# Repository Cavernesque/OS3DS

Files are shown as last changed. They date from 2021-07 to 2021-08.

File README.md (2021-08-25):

# Open Source 3D Scanner - OS3DS

The Open Source 3D scanner is a project with the aims to develop a low-cost, open source hardware and software 3D LiDAR scanner.
This project is an academic research project with MacEwan University, with funding from the Office of Research Services Undergraduate Student Research Initiative Grant (USRI).

### The Project Team

The project team consists of:

- Darren Paetz - Software and Electrical design
- Matt Kantor - Mechanical and Software design
- Dr. Philip Mees - Project Mentor
- Dr. Jeffrey Davis - Project Mentor

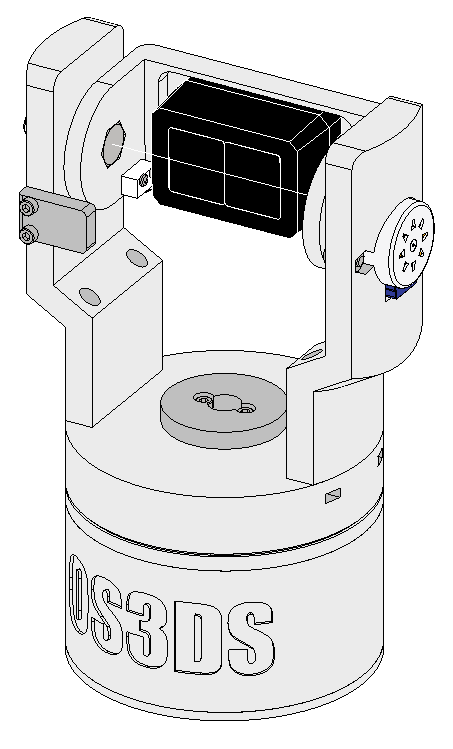
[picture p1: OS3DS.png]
The OS3DS


## The Hardware

The OS3DS has several key hardware components.

It has an Arduino Uno for I/O management, the Benewake TF-02 Pro/Mini Plus for LiDAR data acquisition, 2 5V 28BYJ-48 Stepper motors (64:1) to control its position, and has a 3D printed (PLA and PETG) enclosure that allows proper cable management and tripod mounting.

All of the 3D models for this project can be found in the Electrical_Mechanical folder.

An electrical schematic is included for reference in construction.

Full details of the hardware design can be found in the Design Report, which is located in the Design_Report folder.

## The Software

The OS3DS firmware is written in the Arduino flavor of C++.

Scanner parameters are fully software configurable from the included application. The application can either be built directly from the included Python module, or can be run from the included compressed .7z archive which includes a .exe build of the application.

The included Python module provides a GUI that you can use to send configuration data to the scanner and also then read the scan data back from the Arduino. It saves scan information in the platform-agnostic and ASTM standardized .E57 format, as well as to a file in ASCII format for manipulation and direct viewing.

##### Python Dependencies
- numpy
- pye57
- serial
- PyQt5

## Contribution
Anyone and everyone is free and encouraged to build upon the work this project has started! If any issues are found, please create an issue so that it can be seen by the project owners and the community.

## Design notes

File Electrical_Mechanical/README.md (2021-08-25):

# Print Settings

MATERIAL:  PETG, ABS, or PLA+ (This is due to heat generated by stepper motors, it may exceed the thermal stability of Standard PLA if the motors stall out) 

NOTES:
For best results, print all parts in the default orientation.
Enclosure_Top, and Rotating_Base MUST be printed at 0.2mm layer height or finer.

## Schematic
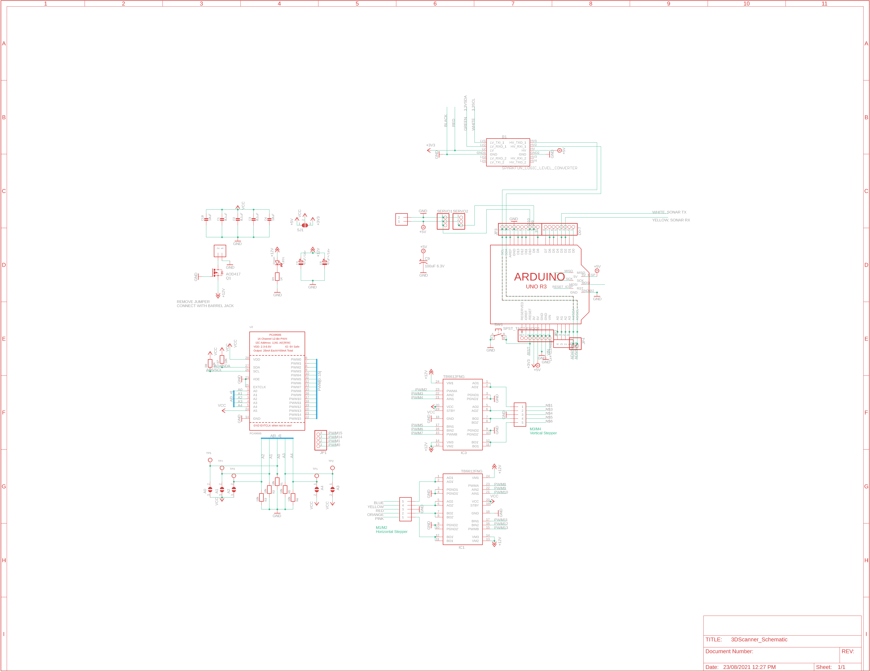
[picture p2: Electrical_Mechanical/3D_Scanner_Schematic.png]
Electrical Schematic


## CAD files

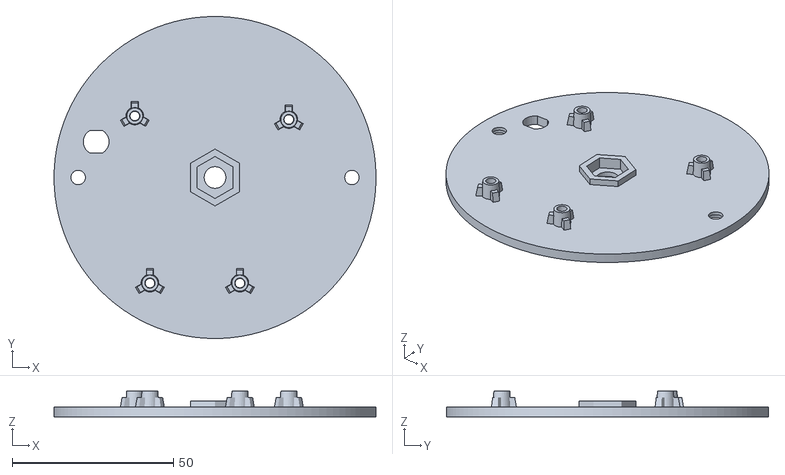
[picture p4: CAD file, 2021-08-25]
Electrical_Mechanical/STL_Files/Base_Plate.stl
100.0 x 100.0 x 8.00

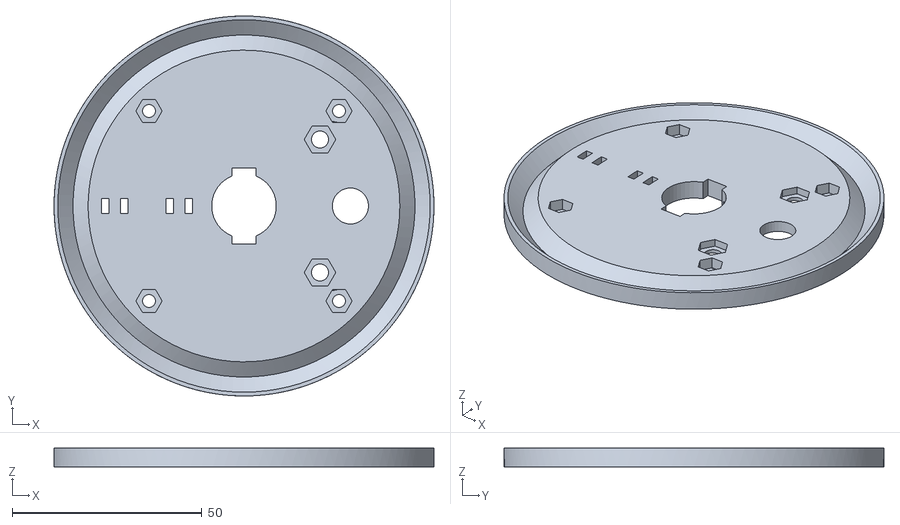
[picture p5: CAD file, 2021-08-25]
Electrical_Mechanical/STL_Files/Enclosure_Top.stl
100.0 x 100.0 x 5.00

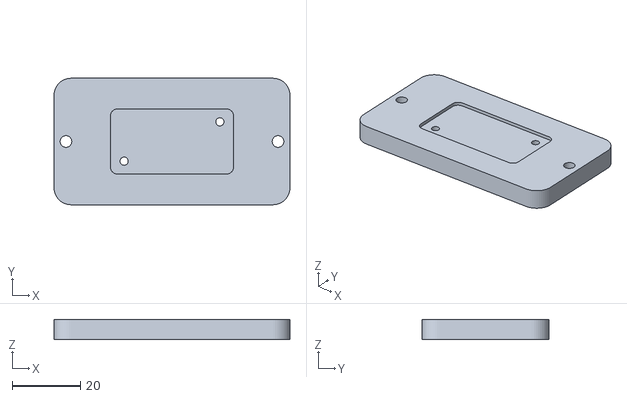
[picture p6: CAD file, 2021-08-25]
Electrical_Mechanical/STL_Files/TFMINI_PLUS_AdapterPlate.stl
69.0 x 37.0 x 5.90

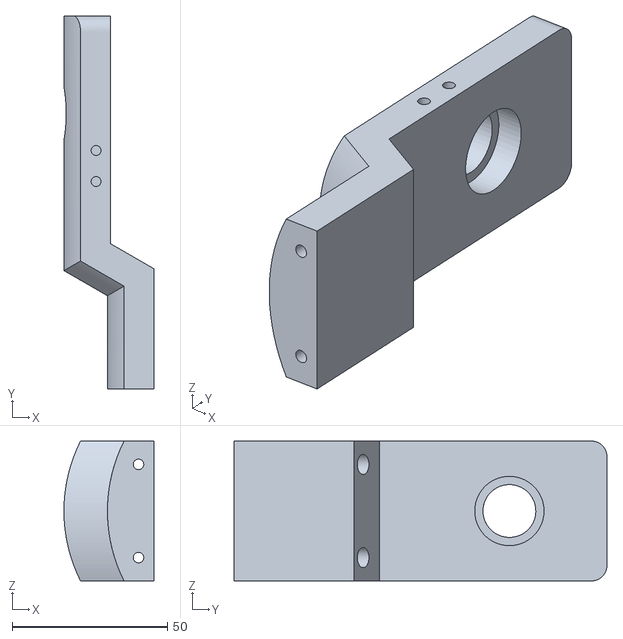
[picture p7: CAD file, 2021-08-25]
Electrical_Mechanical/STL_Files/BearingArm.stl
29.0 x 120.0 x 45.0

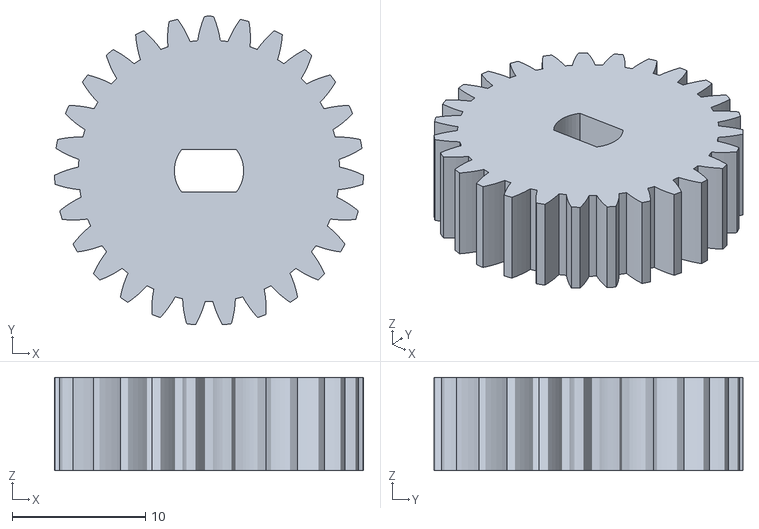
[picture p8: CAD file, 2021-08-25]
Electrical_Mechanical/STL_Files/Spur _Gear.stl
23.2 x 23.2 x 7.00

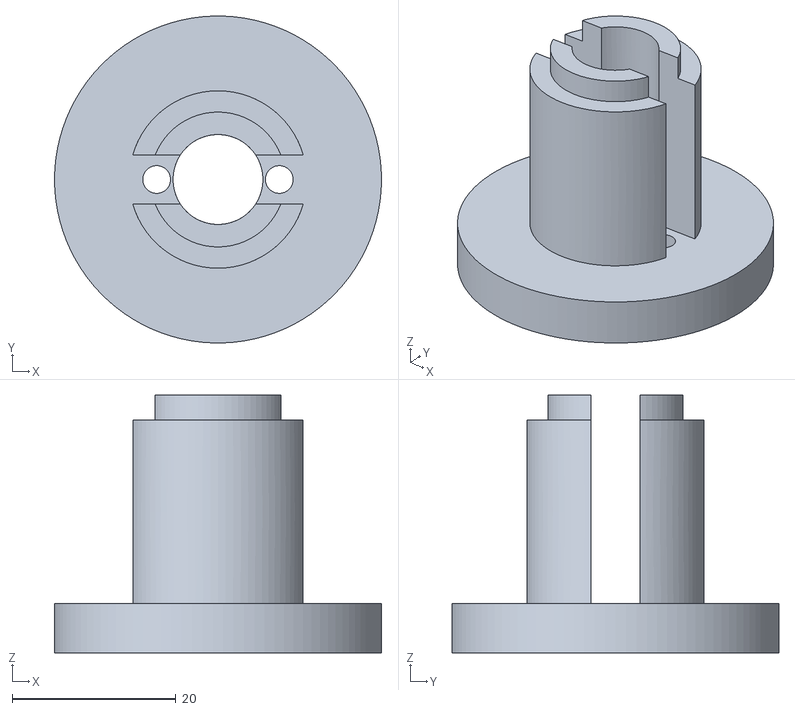
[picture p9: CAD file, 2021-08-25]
Electrical_Mechanical/STL_Files/Shaft.stl
40.0 x 40.0 x 31.5

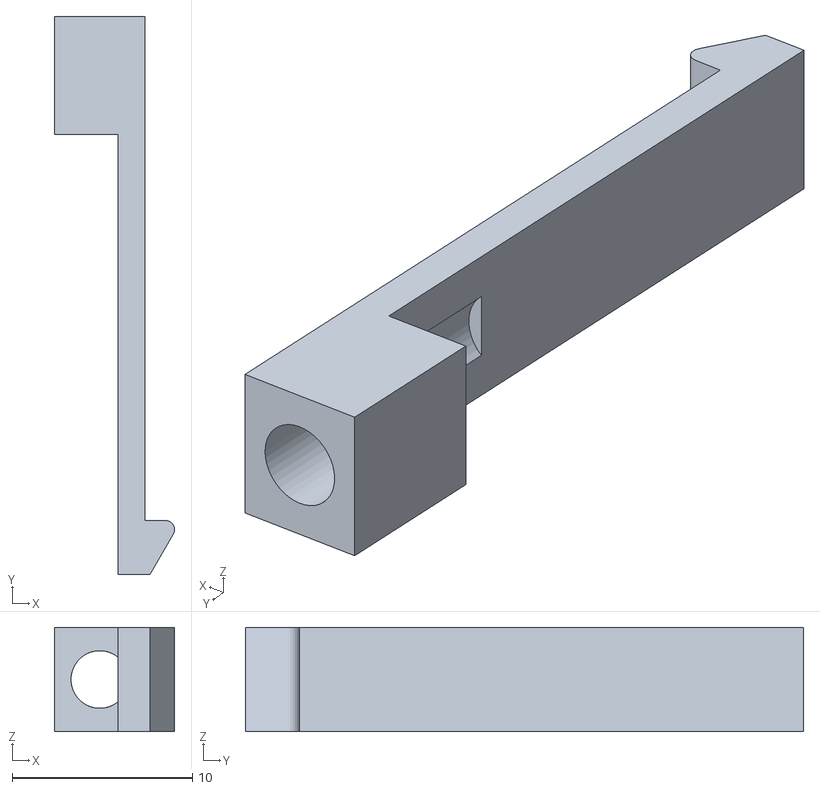
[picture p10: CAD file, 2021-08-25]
Electrical_Mechanical/STL_Files/Shaft Hook.stl
6.68 x 31.0 x 5.80

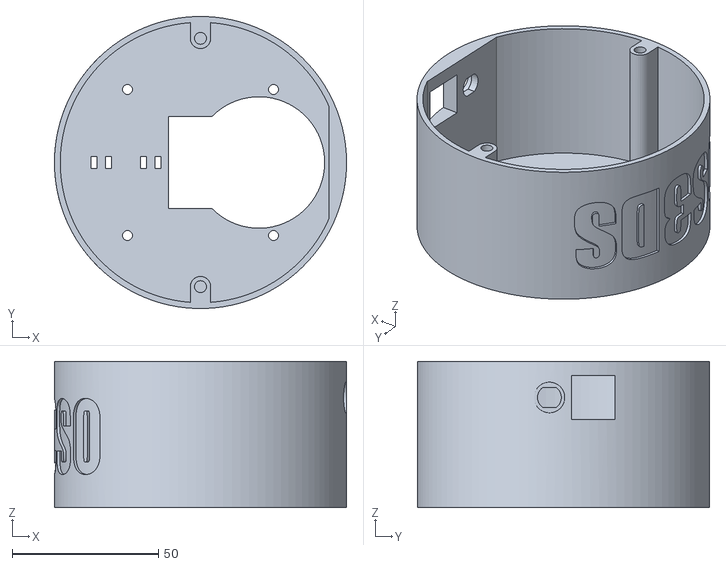
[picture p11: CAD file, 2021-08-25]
Electrical_Mechanical/STL_Files/Enclosure_Body.stl
100.0 x 100.0 x 50.0

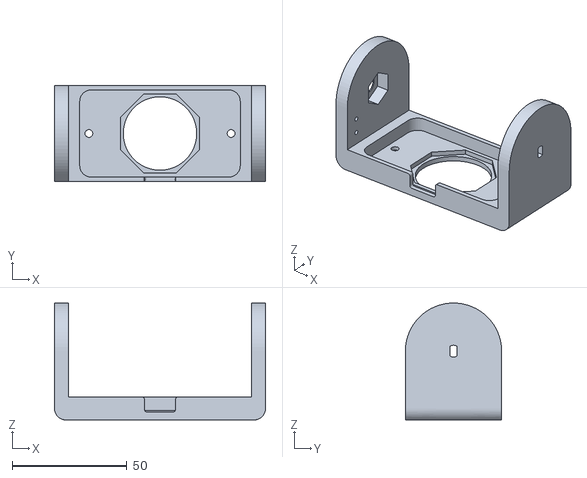
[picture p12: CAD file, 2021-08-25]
Electrical_Mechanical/STL_Files/Sensor_Brkt.stl
92.0 x 42.0 x 51.0

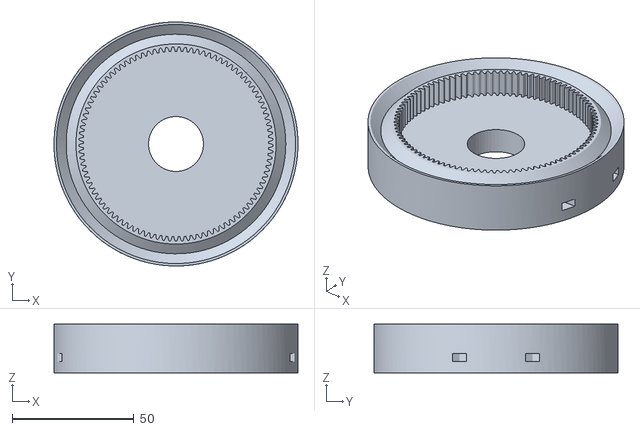
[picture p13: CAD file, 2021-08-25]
Electrical_Mechanical/STL_Files/Rotating_Base.stl
100.0 x 100.0 x 20.0

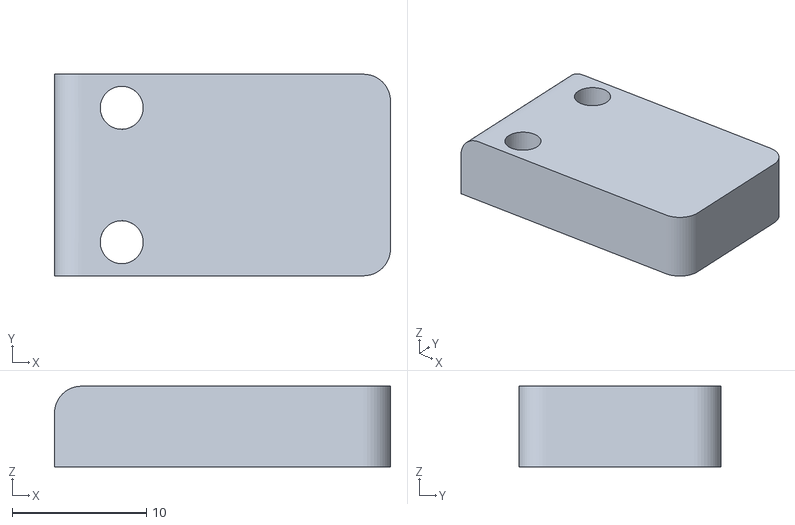
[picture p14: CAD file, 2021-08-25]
Electrical_Mechanical/STL_Files/Endstop_Block.stl
25.0 x 15.0 x 6.00

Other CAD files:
Electrical_Mechanical/STL_Files/Stepper_Arm.stl

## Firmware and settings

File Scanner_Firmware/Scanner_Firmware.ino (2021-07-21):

/*
 * Open-Source 3D Scanner Project
 * Summer 2021
 * Darren Paetz, Matt Kantor, Philip Mees
 * MacEwan University, Edmonton, Alberta, Canada, 2021
 * 
 * This firmware is designed to be used with the 3D Scanner Interface application.
 * That application will gather the data from the scanner and convert it to an
 * industry standard file format (E57).
 * 
 * 
 */

#include <Wire.h>
#include <Adafruit_MotorShield.h>
#include <SoftwareSerial.h>

/***************
  Globals
***************/
// --Scanner--
// Parameters
unsigned int sensor_type = 0; // Parameterization from app - MEMSAVE: byte
unsigned int scan_angle = 0; // Parameterization from app
float scan_resolution = 0; // Parameterization from app
// Scanner angle limits
//  Angle phi is measured downwards from the zenith, relative to the vertical axis of the scanner
//  Straight up (Zenith) -> 0°   Straight down (Nadir) -> 180°
//  Max vertical (highside_angle): 0, but realistically should be 15 degrees.
//  Min vertical (lowside_angle): 150, limited by scanner body.
unsigned int highside_angle = 20;  // Parameterization from app
unsigned int lowside_angle = 135;  // Parameterization from app
unsigned int scan_point_trimming = 0;  // Parameterization from app
unsigned int scan_data_validation = 0; // Parameterization from app
// Scanner data collection
unsigned int distance = 0; // Distance will be used by either sensor type, and takes the same form in memory.
unsigned int intensity = 0; // Strength will be used exclusively by the LiDAR, both TF02 Pro and TFMini
// Scan statistics and flags
bool scan_complete = false;  // Flag for scan completion status
bool scanner_configured = false;  // Flag for scanner successful configuration
byte scanner_current_line = 1;  // Tracks current line to adjust for point interpolation.
unsigned int scan_points_acquired = 0;  // Tracks how many points have currently been scanned.
unsigned long anticipated_points = 0;  // Calculated number of points scan parameters should yield.
unsigned int validation_fails = 0;  // Tracks amount of failed transmissions from sensors
unsigned long vertical_step_cnt = 0;  // Tracks the number of steps to travel back to the top

// ----External Devices----
// --Steppers--
// We'll be using the steppers in full step mode, meaning we get 2037 steps per revolution
// This is based on independent findings that the 28BYJ-48 stepper has 4074 steps per full revolution in half step mode
const int revolution_steps = 2037; // 2037 steps per revolution of stepper (11.311 degrees/64:1 gear ratio)
const float horiz_deg_steps = 20.0871; // 20.0871 steps per horizontal degree (with scanner gearing)
const float vert_deg_steps = 5.6583; // 5.6583 steps per vertical degree (only stepper gearing)
const int full_steps = 7342; // 7342 steps per full horizontal revolution of scanner
float horiz_position = 0; // Initialize horizontal position tracking variable
float vert_position = 90; // Initialize vertical position tracking variable, will be set during homingSequence
bool vert_motor_direction = true; // Vertical motor direction: False is up, True is down

// --LiDAR--
// Default address of the LiDAR is 0x10 (DEC: 16)
// MEMSAVE: Place only in PROGMEM
int lid_addr = 0x10; // Leave as variable so it can be configured to prevent address collisions

/********************
 Stepper object setup
********************/
//Use default I2C addr 0x60 (DEC: 96)
Adafruit_MotorShield AFMS = Adafruit_MotorShield(); 
//Create stepper object with (Steps/rev,Motor Port) on Motor Port 1 (M1&M2) and 2 (M3&M4) 
Adafruit_StepperMotor *horiz_Stepper = AFMS.getStepper(revolution_steps,1); 
Adafruit_StepperMotor *vert_Stepper = AFMS.getStepper(revolution_steps,2);

/******************
 Physical I/O setup
******************/
// Reserve serial connection for the sonar if used
SoftwareSerial sonar_Serial(2,3); // RX 2, TX 3
// Limit switch for vertical axis
const int limit_pin = 7;

/*****************
 Initial functions
*****************/
void setup() {
  // Open serial connection to the application.
  Serial.begin(115200);
  // We'll always need motorshield communication, start it immediately.
  AFMS.begin();
  // Default Stepper Speed is 10 RPM
  horiz_Stepper->setSpeed(10);  // TEST: Change to 15 rpm?
  vert_Stepper->setSpeed(10);  // TEST: Change to 15 rpm?
  // Set pins for limit switch and sonar serial connection
  pinMode(limit_pin, INPUT_PULLUP);
  pinMode(2, INPUT);
  pinMode(3, OUTPUT);
}

void serialEvent(){
  /*  The first character of any serial transmission will be a command code.
   *  A: Configure scanner
   *  B: Jog motors
   *  C: Scan
   *  D: Rangefind
   *  serialEvent is only called at the end of loop(), so we don't need to worry about
   *  potentially interfering with a configuration frame once in that function.
   */
  char command_code = (char)Serial.read();
  switch(command_code){
    case 65:
      codeAConfigure();
      break;
    case 66:
      codeBJog();
      break;
    case 67:
      codeCScan();
      break;
    case 68:
      codeDRangefind();
      break;
  }
}

/***************************
 Configuration (A) functions
***************************/

void codeAConfigure(){
  bool get_config = false, begin_scan = false;
  // Purge the serial buffer to prepare to read configuration data
  while(Serial.available()){
    char byte_dump = Serial.read();
  }
  // Until we can successfully read a configuration frame from the application, do nothing.
  while(get_config == false){
    get_config = getConfiguration();
  }
  // Until we can successfully get a confirmation message from the application, do nothing.
  while(begin_scan == false){
    begin_scan = confirmScan();
  }
  // We've configured successfully, proceed to scan. Set the serial timeout to match the application.
  Serial.setTimeout(500);
  // sensor_type 0 -> SONAR
  //             1 -> LiDAR
  switch(sensor_type){
    case 0: // Sonar
      pinMode(2,INPUT);
      pinMode(3,OUTPUT);
      sonar_Serial.begin(9600);
      sonar_Serial.listen();
      break;
    case 1: // Lidar
      // Begin takes the argument of the Slave address for Arduino to take
      // If no address is given, it joins the I2C bus as a Master
      Wire.begin();
      // Set the wire clock to Fast mode, 400kbps
      Wire.setClock(400000);
      // Set up I2C communication mode to LiDAR
      Wire.beginTransmission(lid_addr);
      // Write the command to change the measurement unit to mm instead of cm
      // HEX: {5A, 05, 05, 06, 6A}     DEC: {90, 5, 5, 6, 106}
      byte message[] = {90, 5, 5, 6, 106};
      Wire.write(message,5);
      // TODO: Add in a message to change the slave address of the I2C if necessary
      // 210618, DP: Likely unnecessary.
      Wire.endTransmission();
      delay(10);  // Wait minimum time for LiDAR response
      break;
  }
  anticipated_points = calcScanPoints();
  homingSequence();
}

bool getConfiguration(){
  /*  Listen on the USB UART for configuration data from the application
   *  Save settings to globals
   *  If data has an invalid parameter, pass back false
   */
  String sensor_string = "", angle_string = "", hiangle_string = "";
  String loangle_string = "", resolution_string = "", valid_string = "", trim_string = "";
  // Set the serial timeout to be very long to allow for potential manual configuration
  // Get configuration data from the application
  // Leave 10ms in between reads to give time for the serial buffer to fill
  Serial.setTimeout(10000);
  sensor_string = Serial.readStringUntil('\n');
  delay(10);
  angle_string = Serial.readStringUntil('\n');
  delay(10);
  hiangle_string = Serial.readStringUntil('\n');
  delay(10);
  loangle_string = Serial.readStringUntil('\n');
  delay(10);
  resolution_string = Serial.readStringUntil('\n');
  delay(10);
  valid_string = Serial.readStringUntil('\n');
  delay(10);
  trim_string = Serial.readStringUntil('\n');
  Serial.setTimeout(1000);
  // Use string methods to pull configuration data from transmission
  sensor_type = (unsigned int)sensor_string.toInt();
  scan_angle = (unsigned int)angle_string.toInt();
  highside_angle = (unsigned int)hiangle_string.toInt();
  lowside_angle = (unsigned int)loangle_string.toInt();
  scan_resolution = (float)resolution_string.toFloat();
  scan_point_trimming = (unsigned int)trim_string.toInt();
  scan_data_validation = (unsigned int)valid_string.toInt();
  
  // Make sure we've changed at least one parameter
  if((scan_angle==0)){
    return false;
  }
  else{
    scanner_configured = true;
    return true;
  }
  return false; // If we've gotten here, something's gone wrong.
}

bool confirmScan(){
  // Take the configuration the scanner has and push it back to the application
  // Once permission is given from application, begin scan.
  // If permission is not granted, pass back false.
  String frame = "", response = "";
  // TODO: Add vertical angle validation
  frame += (String(sensor_type) + ','
    + String(scan_angle) + ','
    + String(highside_angle) + ','
    + String(lowside_angle) + ','
    + String(scan_data_validation) + ','
    + String(scan_point_trimming));
  Serial.println(frame);
  // Set serial timeout long for potential manual configuration
  Serial.setTimeout(10000);
  delay(10);
  response = Serial.readStringUntil('\n');
  Serial.setTimeout(1000);
  if(response == "scan"){
    return true;
  }
  else{
    return false;
  }
  return false; // If we've gotten here, something has gone wrong.
}

void homingSequence(){
  // Initialize the position of the vertical stepper motor
  // Rotate CCW until the limit switch activates
  // Once limit switch is hit, move CW to the highest possible scan angle
  bool limit_state = false;
  // limit_pin is HIGH when switch is closed and closed to ground
  limit_state = !digitalRead(limit_pin);
  // Increment the motor 1 degree in the FORWARD direction until we close the limit switch
  while(!limit_state){
    vert_Stepper->step(20,FORWARD,DOUBLE);  // TEST: Change to smaller step value
    limit_state = !digitalRead(limit_pin);
  }
  // Limit switch reached, go BACKWARD to top vertical angle
  int init_pos_steps = vert_deg_steps*highside_angle;  // TEST: Angle that scanner reaches after taking the steps
  vert_Stepper->step(init_pos_steps,BACKWARD,DOUBLE);
  vert_position = highside_angle;
}

unsigned long calcScanPoints(){
  // Calculate the number of points we should be scanning
  unsigned long points = 0;
  // TODO: Re-introduce point trimming calculation
  // Steps : Resolution
  // (1 : 4.0), (2 : 2.0), (5 : 1.0), (11 : 0.5), (22 : 0.25), (56 : 0.1)
  unsigned int prc_adj_vert_step = vert_deg_steps/scan_resolution;
  // (4 : 4.0), (10 : 2.0), (20 : 1.0), (40 : 0.5), (80 : 0.25), (200 : 0.1)
  unsigned int prc_adj_horiz_step = horiz_deg_steps/scan_resolution;
  // Position change (Degrees) : Resolution
  // (0.1767 : 4.0), (0.3535 : 2.0), (0.8837 : 1.0), (1.944 : 0.5), (3.888 : 0.25), (9.897 : 0.1)
  float prc_adj_vert_pos = prc_adj_vert_step*(1/vert_deg_steps);
  // (0.1991 : 4.0), (0.4978 : 2.0), (0.9957 : 1.0), (1.991 : 0.5), (3.983 : 0.25), (9.957 : 0.1)
  float prc_adj_horiz_pos = prc_adj_horiz_step*(1/horiz_deg_steps);
  unsigned long vertical_positions = ((lowside_angle-highside_angle)/prc_adj_vert_pos) + 1; // Add 1 to ensure we go over the angle limit
  unsigned long horizontal_positions = (scan_angle/prc_adj_horiz_pos) + 1; // Add 1 to ensure we go over the angle limit
  points = vertical_positions*horizontal_positions;
  return points;
}

/*****************
 Jog (B) functions
*****************/

void codeBJog(){
  /*  Each jog button will only send a single character on UART.
   *  Wait to receive it from the application.
   */
  delay(100);
  char direct_code = (char)Serial.read();
  switch(direct_code){
    // Each button press should correspond to 4 degrees of turn
    // TODO: This amount of steps should be configurable.
    case 117:  // 'u'
      vert_Stepper->step(20,FORWARD,DOUBLE);
      break;
    case 100:  // 'd'
      vert_Stepper->step(20,BACKWARD,DOUBLE);
      break;
    case 108:  // 'l'
      horiz_Stepper->step(80,BACKWARD,DOUBLE);
      break;
    case 114:  // 'r'
      horiz_Stepper->step(80,FORWARD,DOUBLE);
      break;
  }
}

/***************************************
 Scan and data acquisition (C) functions
***************************************/

void codeCScan(){
  // Loop until we have enough points to satisfy the scan.
  while(!scan_complete){
    bool data_state = false;
    bool scan_the_point = false;
    // ----------------------------------
    // Gather data from configured sensor
    // ----------------------------------
    // If point interpolation enabled, check if we need to measure a point at the current scanner position.
    scan_the_point = scanPoint();
    if(scan_the_point){
      // LiDAR routine
      if((sensor_type) && (!scan_complete)){
        data_state = readLidar();
        // If we are not using data validation, and the data is invalid, pass 0's.
        if((!scan_data_validation) && (!data_state)){
          distance = 0;
          intensity = 0;
          data_state = true; // Pass a true data state so program proceeds.
        }
        // Otherwise, we're using data validation and need to continue polling sensor until we get a good value
        else{
          while(!data_state){
            data_state = readLidar();
          }
        }
      }
      // Sonar routine
      else if((!sensor_type) && (!scan_complete)){
        data_state = readSonar();
        // If we are not using data validation, and the data is invalid, pass 0.
        if((!scan_data_validation) && (!data_state)){
          distance = 0; // Sonar doesn't yield intensity.
          data_state = true; // Pass a true data state so program proceeds.
        }
        // Otherwise, we're using data validation and need to continue polling sensor until we get a good value
        else{
          while(!data_state){
            data_state = readSonar();
          }
        }
      }
    }
    // Increment our point count, irrespective of data validity condition
    scan_points_acquired += 1;
    /*  Push data
     *  If data validation is enabled, and the data is bad, loop and try reading data again. App will wait.
     *  Data frame is structured as:
     *  DATA: Distance, Itensity, Horizontal angle, Vertical angle, Checksum
     *  TYPE: unsigned int, unsigned int, float, float, unsigned long
     *  UNIT: [mm], [value], [angle°], [angle°], [integer]
     */
    if(data_state){
      unsigned long checksum = genChecksum();
      Serial.print(distance);
      Serial.print(',');
      Serial.print(intensity);
      Serial.print(',');
      Serial.print(horiz_position);
      Serial.print(',');
      Serial.print(vert_position);
      Serial.print(',');
      Serial.print(checksum);
      Serial.print('\r');
      Serial.print('\n');
    }
    else
    {
      Serial.print("0,0,0,0,0");
      Serial.print('\r');
      Serial.print('\n');
    }
    // Move the scanner to the next position.
    moveScanner();
    // Check to see if the scan has completed, set the flag if it is.
    if(scan_points_acquired >= anticipated_points){
      scan_complete = true;
    }
  }
  // Return to starting position after loop is finished, "anti-tangle"
  horiz_Stepper->step((full_steps*(horiz_position/360)),FORWARD,DOUBLE); // Rotate horizontally clockwise
  horiz_position = 0;
  // Scan is complete, pass control back to loop() and allow serial commands again.
  Serial.print("complete,");
  if(scan_data_validation){
    Serial.println(validation_fails);
  }
  else{
    Serial.println("0");
  }
  horiz_Stepper->release();
  vert_Stepper->release();
}

void moveScanner(){
  /*  Take scan parameters and move the steppers accordingly
   *  How many steps the motor moves between data points is dependent on scan resolution
   *  When method returns true, scan is complete.
   *  (Scan resolution : Vertical points per horizontal position)
   *  (2.0 : 180), (1.0 : 90), (0.5 : 45), (0.25 : 22), (0.1 : 9)
   *  Scan resolution : Horizontal degrees in full rotation
   *  (2.0 : 720), (1.0 : 360), (0.5 : 180), (0.25 : 90), (0.1 : 36)
   * INFO: There is theoretically an available "extremely fine" scan where we take 11 data points per degree
   *       This would mean 990 points per horizontal degree, and 3960 horizontal points
   *       A whopping total of 3.92 MILLION points!
   */
  // Steps : Resolution
  // (1 : 4.0), (2 : 2.0), (5 : 1.0), (11 : 0.5), (22 : 0.25), (56 : 0.1)
  int prc_adj_vert_step = vert_deg_steps/scan_resolution;
  // (4 : 4.0), (10 : 2.0), (20 : 1.0), (40 : 0.5), (80 : 0.25), (200 : 0.1)
  int prc_adj_horiz_step = horiz_deg_steps/scan_resolution;
  // Position change (Degrees) : Resolution
  // (0.1767 : 4.0), (0.3535 : 2.0), (0.8837 : 1.0), (1.944 : 0.5), (3.888 : 0.25), (9.897 : 0.1)
  float prc_adj_vert_pos = prc_adj_vert_step*(1/vert_deg_steps);
  // (0.1991 : 4.0), (0.4978 : 2.0), (0.9957 : 1.0), (1.991 : 0.5), (3.983 : 0.25), (9.957 : 0.1)
  float prc_adj_horiz_pos = prc_adj_horiz_step*(1/horiz_deg_steps);
  // Control the vertical motor based on the direction we need to travel
  switch(vert_motor_direction){
    case 0: // Rotate servo upwards
      vert_Stepper->step(vertical_step_cnt,FORWARD,DOUBLE);
      vert_position = highside_angle;
      vertical_step_cnt = 0;
      vert_motor_direction = !vert_motor_direction;
      break;
    case 1: // Rotate servo downwards
      vert_Stepper->step(prc_adj_vert_step,BACKWARD,DOUBLE);
      vert_position += prc_adj_vert_pos;
      vertical_step_cnt += prc_adj_vert_step;
      break;
  }
  if(vert_position >= lowside_angle){
    horiz_Stepper->step(prc_adj_horiz_step,BACKWARD,DOUBLE); // Rotate horizontally anti-clockwise
    horiz_position += prc_adj_horiz_pos;
    vert_motor_direction = !vert_motor_direction;
    // Cycle the scanner line around the pattern
    if(scanner_current_line >= 8){
      scanner_current_line = 1;
    }
    else{
      scanner_current_line += 1;
    }
  }
  return;
}

bool readLidar() {
  /*  Read distance information from the Benewake TF02 Pro or TF Mini Plus
   *  Information is communicated over I2C bus at 400 kbps (Fast Mode), must be requested
   *  When data is read successfully, write it to the global variable
   */
  distance = 0;
  byte i = 1;  // Iterator for dataframe from lidar
  byte b = 0;  // Byte holder for dataframe from lidar
  word checksum = 0;
  bool check_pass = false;
  // Set up the delay time between request and read from the LiDAR on I2C
  const byte lid_dly = 10; // Value shouldn't change, make constant
  Wire.beginTransmission(lid_addr);
  /*  The write command will send a request to the LiDAR to obtain a data frame
   *  Measurement will change based on command
   *  HEX: {5A 05 00 01 60} will give cm
   *  DEC: {90 5 0 1 96}
   *  HEX: {5A 05 00 06 65} will give mm
   *  DEC: {90 5 0 6 101} 
   */
  byte data_req_from_lid[] = {90, 5, 0, 6, 101};
  Wire.write(data_req_from_lid,5);
  // endTransmission by default ends with a "stop" message on the I2C bus - the Pro and Mini require this message to be present
  Wire.endTransmission();
  // It's recommended that after initiating a request for data that you wait 100ms before reading the response
  // However, this can be reduced dramatically, to near 10ms to allow for fast data acquisition
  delay(lid_dly);
  // Request the slave write the data frame onto the bus
  Wire.requestFrom(lid_addr,9);
  // Read the response from the LiDAR, interpret it and push it.
  while(Wire.available()){
    // Get the next available byte
    b = Wire.read();
    // Bytes 3 and 4 are the distance data bytes, process them
    if(i==3){
      distance = b;
    }
    if(i==4){
      // Correct for Little Endian format, and add to the total
      distance = distance + (b << 8);
    }
    // Bytes 5 and 6 are the signal strength data bytes, process them
    if(i==5){
      intensity = b;
    }
    if(i==6){
      // Correct for Little Endian format, and add to the total
      intensity = intensity + (b << 8);
    }
    // If this isn't the checksum byte from LiDAR, add it to the local checksum
    if(i != 9){
      checksum += b;
    }
    // Otherwise, we are looking at the checksum byte. Validate our checksum against it.
    // If our checksum matches, we've received the data correctly. Push it to serial.
    // Return whether the checksum matched or not to the main program.
    else{
      if(lowByte(checksum) == b){
        // If the data matches the LiDAR checksum, data is good.
        check_pass = true;
      }
      else{
        // We've failed a checksum validation, add to the statistics.
        validation_fails += 1;
      }
      // The return value of the function will dictate if we use the data or not.
      return check_pass;
    }
    // Increment byte counter
    i++;
  }
  return false; // If we've gotten here, something went wrong with the I2C. Don't use the data.
}
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
void loop() {
}

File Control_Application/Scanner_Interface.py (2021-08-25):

"""A module that creates the GUI application for the Open-Source Scanner.

Open-Source 3D Scanner Project
Created by: Darren Paetz, Matt Kantor, Dr. Philip Mees
MacEwan University, Edmonton, Alberta, Canada, 2021

This application is designed to be used with an Arduino-based 3D scanner.
The firmware running on the Arduino will communicate with this application,
allowing the application to convert sensor data into an ASTM standard 3D-scan
file format (E57).

This project was made possible with the following funding:
    MacEwan University's Undergraduate Student Research Initiative Grant (USRI)

"""

import sys
import pye57
import numpy as np
import math
import serial
import serial.tools.list_ports
from time import sleep
from datetime import datetime
from PyQt5 import QtWidgets, uic
import uuid

from typing import Dict
from pye57.__version__ import __version__
from pye57 import libe57

qtcreator_file = "3D_Scan_App_UI.ui"  # Load the ui file
Ui_MainWindow, QtBaseClass = uic.loadUiType(qtcreator_file)

SUPPORTED_POINT_FIELDS = {
    "cartesianX": "d",
    "cartesianY": "d",
    "cartesianZ": "d",
    "intensity": "f",
    "colorRed": "B",
    "colorGreen": "B",
    "colorBlue": "B",
    "rowIndex": "H",
    "columnIndex": "H",
    "cartesianInvalidState": "b",
}


class MainWindow(QtWidgets.QMainWindow, Ui_MainWindow):
    """Application GUI object.

    Inherits from QtWidgets.QMainWindow.

    """

    def __init__(self):
        """Initialize the application window object.

        Connect the signal and slots of the various objects within the GUI.
        Initialize the scan points and scan time labels with zeros.

        Returns
        -------
        None.

        """
        QtWidgets.QMainWindow.__init__(self)
        Ui_MainWindow.__init__(self)
        self.setupUi(self)

        # Initialize the properties of scan points and estimated time
        self.scan_point_count = 0
        self.scan_time_estimate = 0

        # Serial communication flag, put serial object in namespace
        self.connected_to_arduino = False
        self.arduino = None
        self.abort_scan = False

        # Lookup table for resolution multipliers
        # Ex Fine, Very Fine, Fine, Medium, Coarse, Very Coarse
        self.resolution_options = [4, 2, 1, 0.5, 0.25, 0.1]

        # Connect the signal slots for the file menu
        self.actionExit_2.triggered.connect(self.close)
        self.actionOpen_Settings_File.triggered.connect(self.loadSettings)
        self.actionSave_Settings_File.triggered.connect(self.saveSettings)
        self.actionAbout_OS3DS.triggered.connect(self.aboutDialog)
        self.actionAbout_Qt.triggered.connect(self.aboutQtDialog)
        self.actionLicense.triggered.connect(self.licenseDialog)

        # Initialize the com ports available to connect from OS
        self.refcomButton.clicked.connect(self.getSerialPorts)

        # Connect all combo boxes to the logic that calculates scan time
        # and number of scan points
        self.angleBox.activated.connect(self.calcScanProperties)
        self.resolutionBox.activated.connect(self.calcScanProperties)

        # Connect the browse for filename button to an open filename dialog
        self.outputfileButton.clicked.connect(self.getE57Filename)

        # Connect the scanner buttons to their respective methods
        self.connectButton.clicked.connect(self.connectToScanner)
        self.scanButton.clicked.connect(self.scan)
        self.abortScanButton.clicked.connect(self.abortScan)

        # Set the scan information with preliminary settings
        self.calcScanProperties()
        self.getSerialPorts()

        # Connect the jog buttons to the jog motor method
        self.jogscannerUp.clicked.connect(
                lambda: self.jogDirection("up"))
        self.jogscannerDown.clicked.connect(
                lambda: self.jogDirection("down"))
        self.jogscannerLeft.clicked.connect(
                lambda: self.jogDirection("left"))
        self.jogscannerRight.clicked.connect(
                lambda: self.jogDirection("right"))

        # Connect the rangefind button to the rangefind method
        self.rangefindButton.clicked.connect(self.rangeFind)

    """
    --------------------------------------------------------------
                File menu methods
    --------------------------------------------------------------
    """

    def loadSettings(self):
        """Load saved settings for the application from a CSV file.

        Returns
        -------
        None.

        """
        options = QtWidgets.QFileDialog.Options()
        # Get the filename of the settings file
        # Discard the filetype that the method returns
        fileName, _ = QtWidgets.QFileDialog.getOpenFileName(
            self, "Open a scanner configuration file", "",
            "Scanner Configuration Files (*.3dscancfg);;All Files (*)",
            options=options)
        if fileName != '':
            with open(fileName, "r") as fh:
                data = fh.readline()
                data = data.split(",")
                self.sensorBox.setCurrentIndex(int(data[0]))
                self.angleBox.setCurrentIndex(int(data[1]))
                self.highAngleBox.setValue(int(data[2]))
                self.lowAngleBox.setValue(int(data[3]))
                self.resolutionBox.setCurrentIndex(int(data[4]))
                self.datavalidationBox.setChecked(bool(data[5]))
                self.pointtrimmingBox.setChecked(bool(data[6]))
            self.calcScanProperties()

    def saveSettings(self):
        """Save current settings for the application to a CSV file.

        Returns
        -------
        None.

        """
        options = QtWidgets.QFileDialog.Options()
        fileName, _ = QtWidgets.QFileDialog.getSaveFileName(
            self, "Save scanner configuration to file", "",
            "Scanner Configuration Files (*.3dscancfg);;All Files (*)",
            options=options)
        if fileName != '':
            with open(fileName, "w") as fh:
                fh.write(repr(self.sensorBox.currentIndex()) + ",")
                fh.write(repr(self.angleBox.currentIndex()) + ",")
                fh.write(repr(self.highAngleBox.value()) + ",")
                fh.write(repr(self.lowAngleBox.value()) + ",")
                fh.write(repr(self.resolutionBox.currentIndex()) + ",")
                fh.write(repr(self.datavalidationBox.isChecked()))
                fh.write(repr(self.pointtrimmingBox.isChecked()))

    def aboutDialog(self):
        """Open the About dialog box.

        Returns
        -------
        None.
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

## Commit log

2021-07-10 Directory structure for firmware
    Made it so Arduino IDE can natively open firmware file
2021-07-11 App updates
    ui angle change, scan point method stability
    [Scanner_Firmware.ino, Scanner_Interface.py]
2021-07-13 License dialog finished
    License dialog correctly works now
    [Scanner_Interface.py]
2021-07-14 Name within E57 conflicts resolved
    When two scans had the same name within the E57 file, AutoDesk ReCap Pro does not want to merge them in the same project. Changed code so that the default name within the E57 is now based on timestamp and settings.
    Changed About dialog box to have more information about intended use of OS3DS.
    [Scanner_Interface.py]
2021-07-14 Scan data sharing
    Added all current scan data. As testing progresses, all scan data will be uploaded to repo.
    [Mesh[180_Cafeteria_Vault_Feature] (level 8)_MESH.obj, Mesh[180_Cafeteria_Vault_Feature_FineRes] (level 8).ply, Mesh[180_Cafeteria_Vault_Feature_FineRes] (level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]
2021-07-15 Reverse logic on end switch
    Reversed end switch logic in homing sequence
    [Scanner_Firmware.ino]
2021-07-15 Changed motor logic
    Directional flip to compensate for wiring changes in stepper motors
    [Scanner_Firmware.ino]
2021-07-16 Scan data upload, change to firmware
    Changed firmware to match stepper direction, and increased torque to improve reliability. Scan data from night's tests added.
2021-07-18 Firmware updates and data
    Update firmware motion control, update application calculated scan time, data from testing
    [Mesh[Stepper_Adjusted_Motion_13] (level 8).stl]
2021-07-19 Upload scan data, updated firmware, application
    Firmware motion algorithm fixed - minor update to scan time estimate with new motion code. Data gathered during last night's session in folders.
    [210718-2125-LiDAR-10-Moderate_scandata.xlsx, Mesh[Living_Room_Partial_View] (level 8).stl]
2021-07-20 Application scan data
    Added testing data from day
    [210718-2125-LiDAR-10-Moderate_scandata.xlsx, Mesh[Dining_Room] (level 8).stl, Mesh[Living_Room_Partial_View] (level 8).stl]
2021-07-20 Move data to correct folder
    Change directories for data
    [Mesh[Dining_Room] (level 8).stl, Mesh[Living_Room_Partial_View] (level 8).stl]
2021-07-21 Sonar data, firmware update for sonar
    Sonar data from testing, and accompanying firmware changes to accommodate sonar data acquisition. Small application update to help debugging output.
2021-07-21 Update Scanner_Interface.py
    Tiny change to ensure text displays in rangefinder box correctly.
    [Scanner_Interface.py]
2021-07-22 Update scanner interface archive with new version
    Updated the .7z archive containing the newest build of the application. Added a photo of the sonar scan.
2021-08-25 Add mechanical files
    Added all mechanical files, update the readme
    [Base_Plate.stl, BearingArm.stl, Enclosure_Body.stl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]
2021-08-25 Remove testing data
    Remove testing data directory
    [210718-2125-LiDAR-10-Moderate_scandata.xlsx, Mesh[180_Cafeteria_Vault_Feature] (level 8)_MESH.obj, Mesh[180_Cafeteria_Vault_Feature_FineRes] (level 8).ply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]
2021-08-30 Update Design Report
    Update design report with final bill of materials in Appendix B
